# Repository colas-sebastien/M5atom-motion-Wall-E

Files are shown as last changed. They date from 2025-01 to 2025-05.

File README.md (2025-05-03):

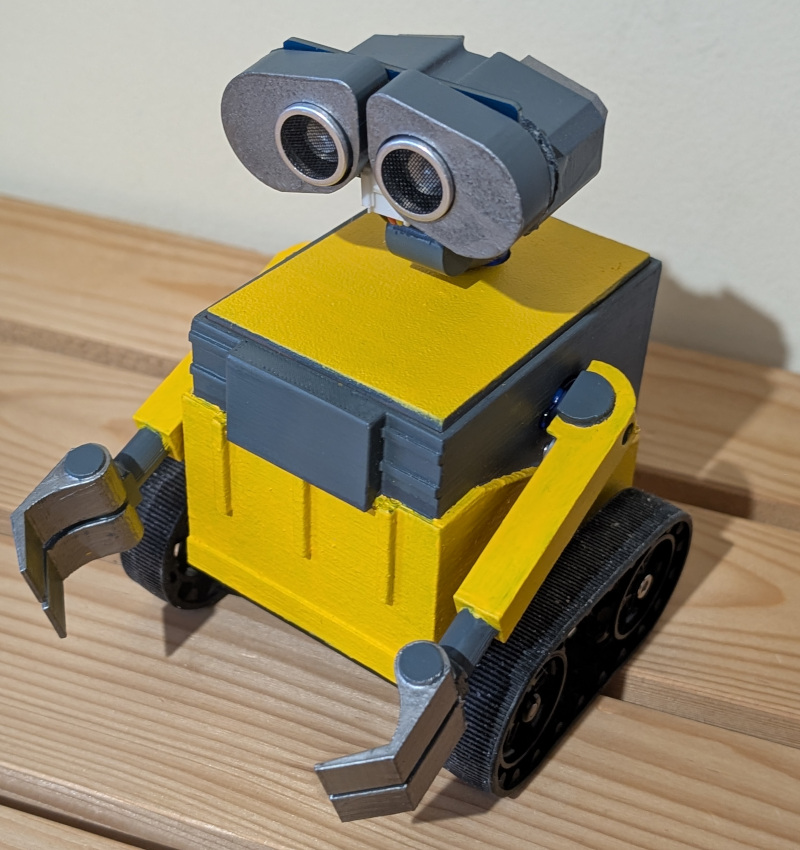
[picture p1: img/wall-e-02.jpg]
M5Atom WALL-E


# M5Atom WALL-E

Create your Wall-E thanks to M5atom

## Hardware
- [1x Zumo Chassis Kit](https://www.pololu.com/product/1418) 
- [2x Micro Metal Gearmotor HP 6V](https://www.pololu.com/product/1101) 
- [Grove - I2C Motor Driver](https://www.seeedstudio.com/Grove-I2C-Motor-Driver-TB6612FNG-p-3220.html) 
- [M5Atom](https://shop.m5stack.com/products/atomic-motion-base-stm32f030?variant=44393917219073) 
- [Atomic Motion Base](https://shop.m5stack.com/products/atom-tailbat) 
- [Battery 16340 2600mAh](https://www.amazon.fr/Rechargeables-Batterie-2800mAh-Capacit%C3%A9-Frontale/dp/B0CTQ4X244)
- [Battery holder for 16340](https://www.amazon.fr/dp/B07MC7WR8J?ref=ppx_yo2ov_dt_b_fed_asin_title)
- [3x ServoMotors sg90](https://www.amazon.fr/dp/B0DFCGXY2J)
- [Grove Ultrasonic distance sensor](https://www.seeedstudio.com/Grove-Ultrasonic-Distance-Sensor.html)
- [A bluetooth gamepad supported by BluePad32 for Arduino](https://gitlab.com/ricardoquesada/bluepad32-arduino) 

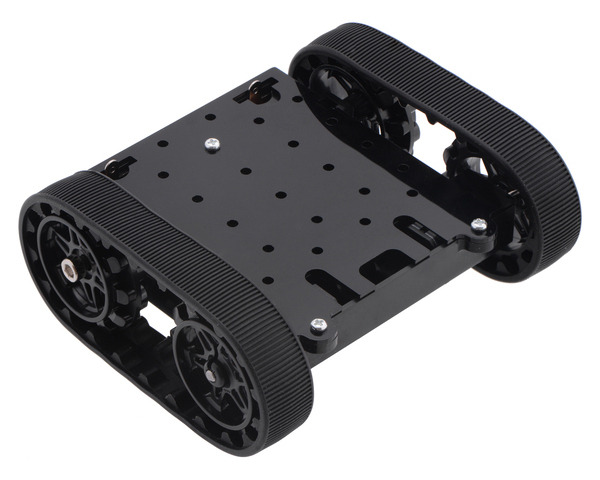
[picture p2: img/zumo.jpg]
zumo

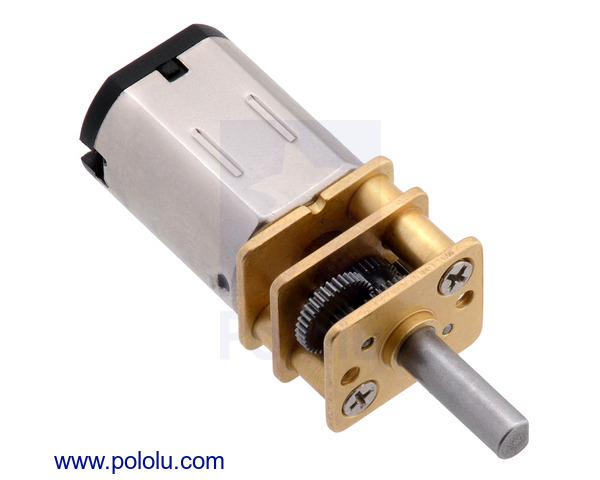
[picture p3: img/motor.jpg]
motor

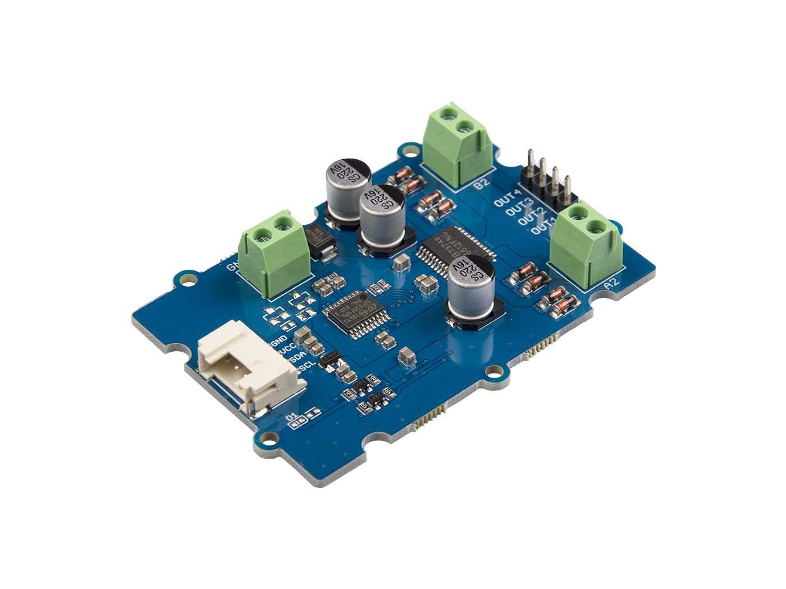
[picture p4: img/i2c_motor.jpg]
I2C motor driver

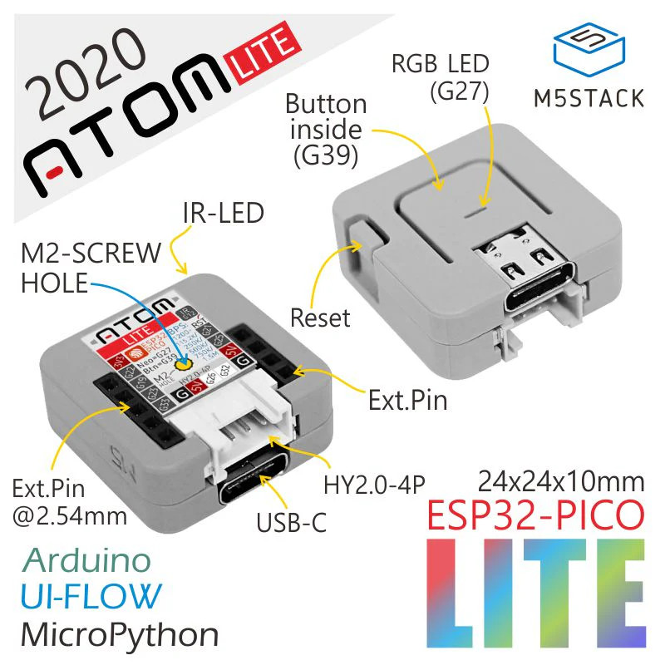
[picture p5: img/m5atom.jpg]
M5Atom lite

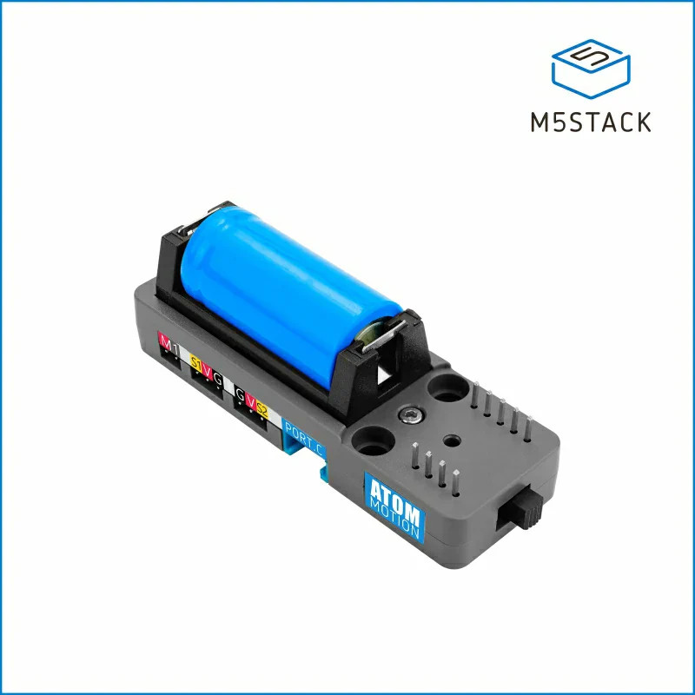
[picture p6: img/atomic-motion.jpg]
Atomic Motion Base

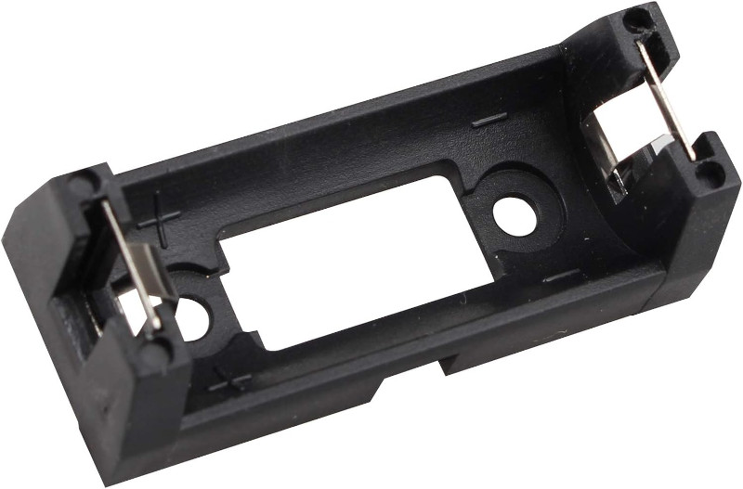
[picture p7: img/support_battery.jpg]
Battery holder for 16340

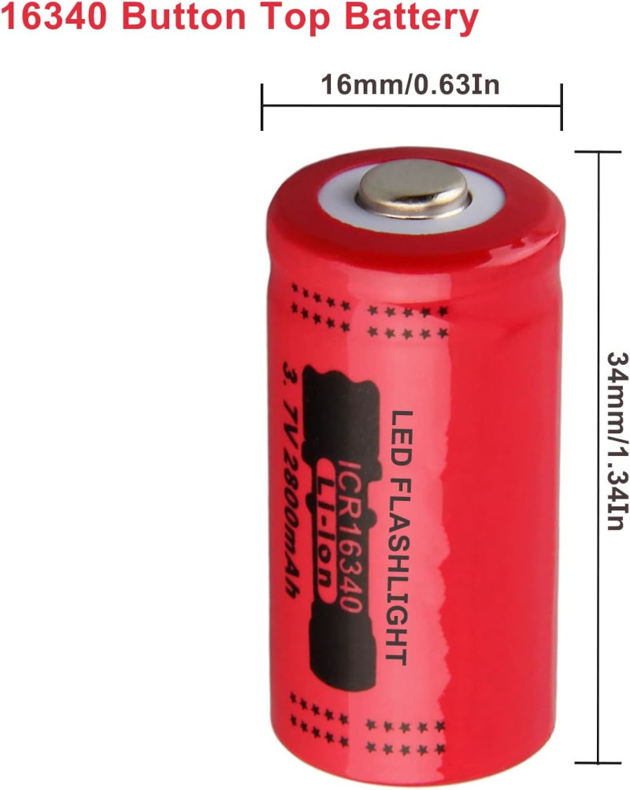
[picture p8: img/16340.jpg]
Battery 16340 2600mAh

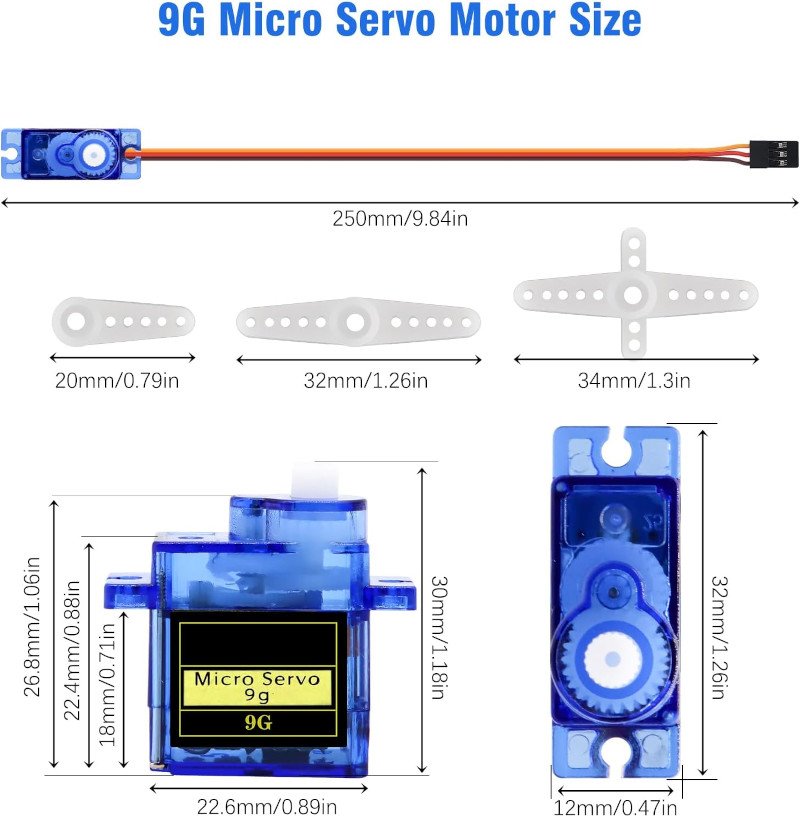
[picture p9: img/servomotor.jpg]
Servo Motor

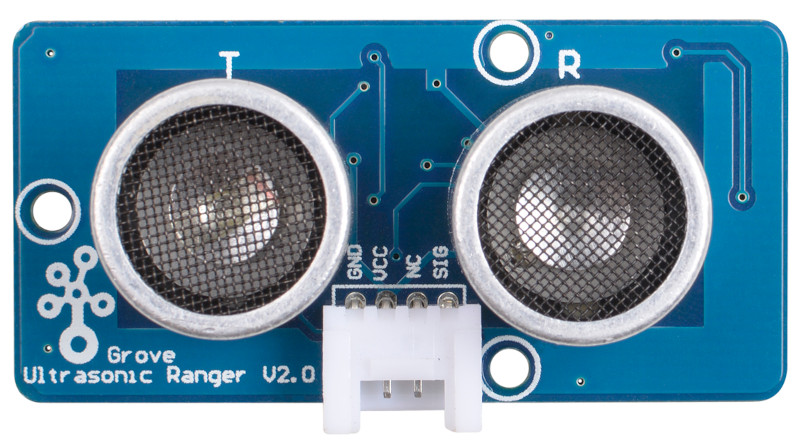
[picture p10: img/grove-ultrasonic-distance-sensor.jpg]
Grove Ultrasonic distance sensor

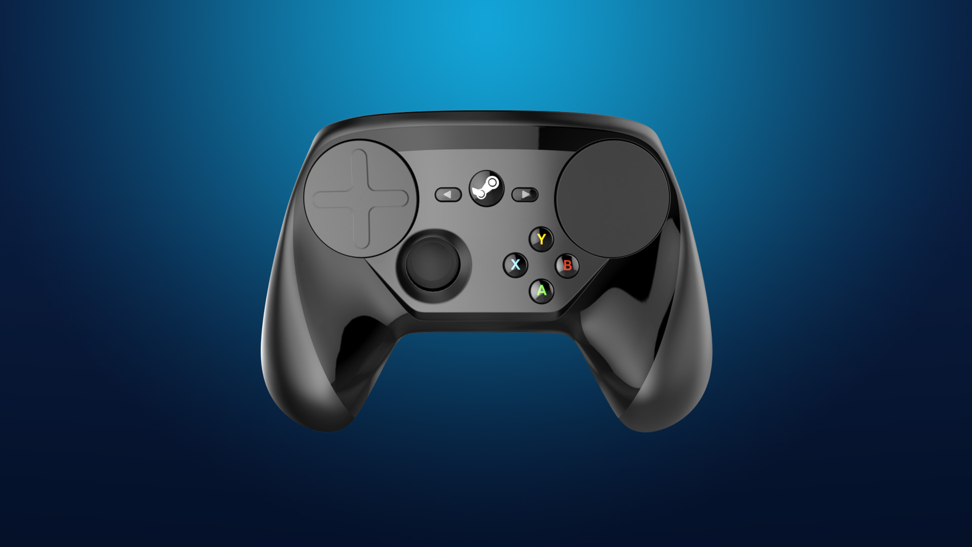
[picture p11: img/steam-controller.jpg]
Steam Controller


## 3D Model
### FreeCAD
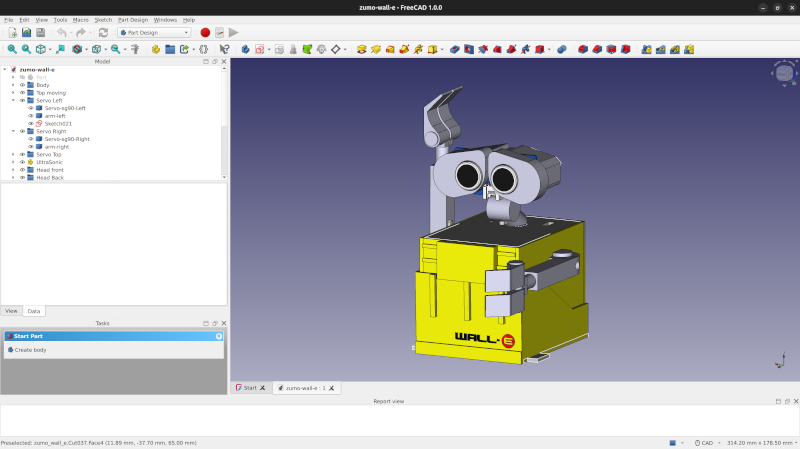
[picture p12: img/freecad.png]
FreeCAD

You can found the FreeCAD model into the *FreeCAD* directory.

### STL
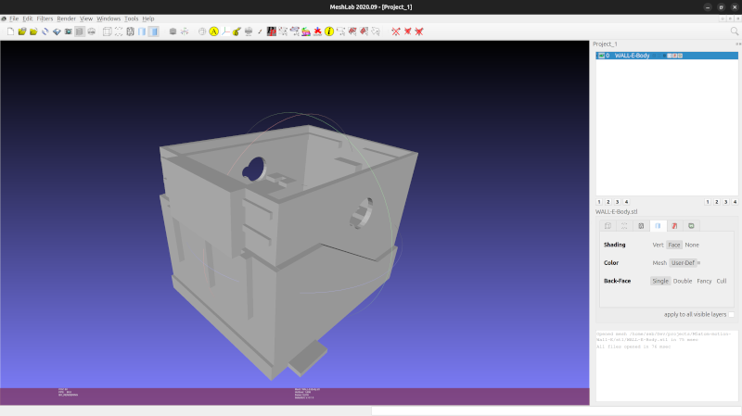
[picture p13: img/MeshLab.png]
MeshLab


You can found the FreeCAD model into the *stl* directory.

## Connect everything together
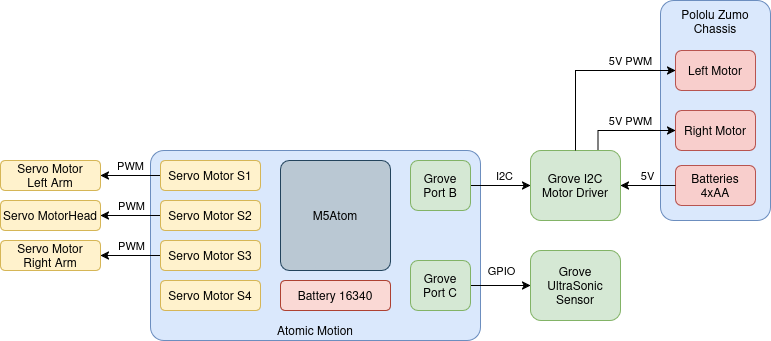
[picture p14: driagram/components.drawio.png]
Connect everything together

### Atomic Motion Modification (optional)
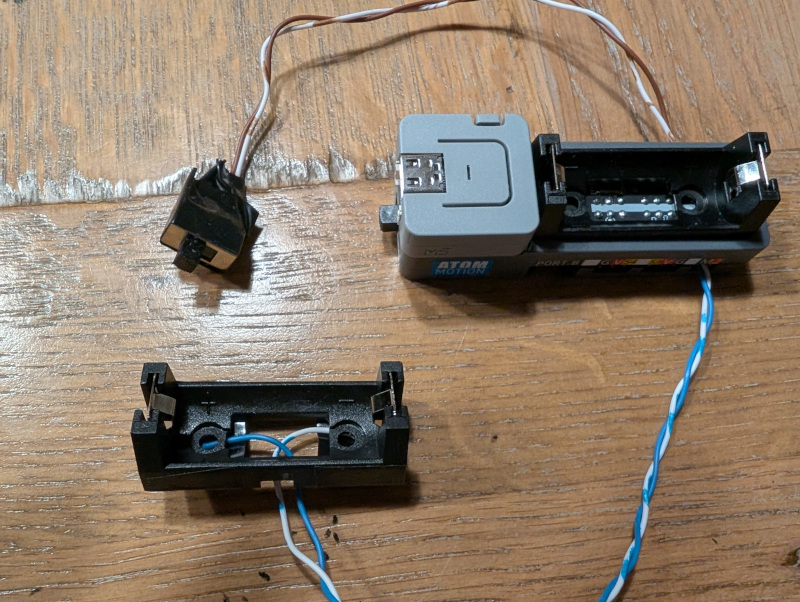
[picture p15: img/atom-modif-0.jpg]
Atom Modification

To power on/off WALL-E and easily replace the battery the following modifications can be on the Atomic module
- Add an external battery holder
- Add an external switch

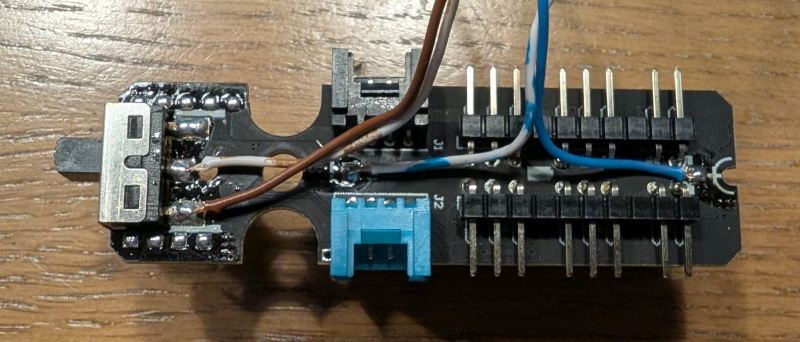
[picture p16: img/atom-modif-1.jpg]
Atom Modification


### Inside WALL-E
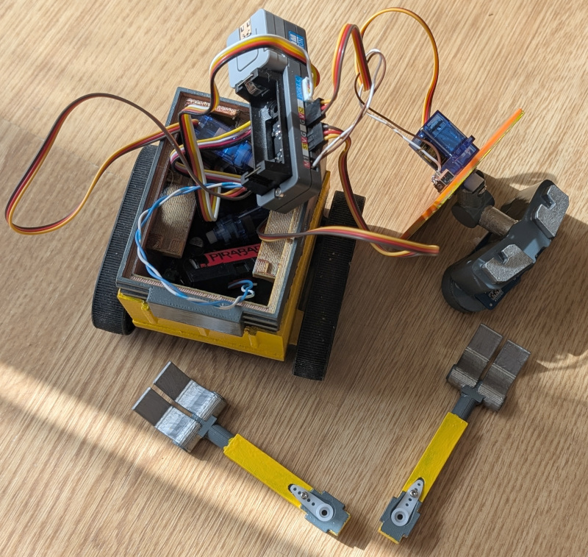
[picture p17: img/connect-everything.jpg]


## Software
- Install thanks to Board Manager: 
    - BluePad for Arduino [BluePad for Arduino](https://bluepad32.readthedocs.io/en/latest/plat_arduino/)
    - M5Stack
- Install thanks to Library Manager:
    - Grove Motor Driver TB6612FNG
    - Grove Ultrasonic Ranger
    - Adafruit NeoPixel
    - M5Atom    
- Select for Board: *ESP32 + Bluepad32 Arduino / M5Stack-ATOM*

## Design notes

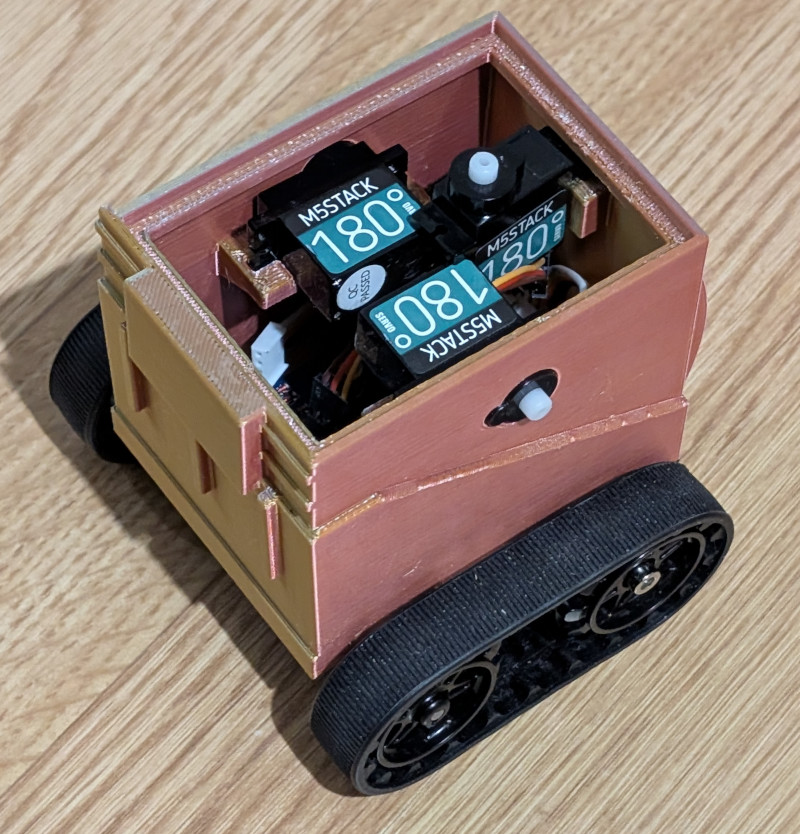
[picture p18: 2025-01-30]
img/wall-e-01.jpg

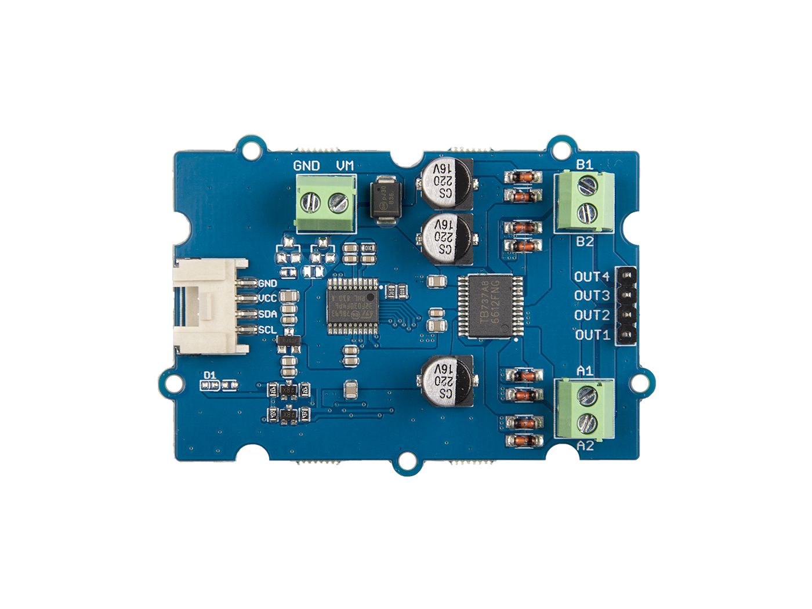
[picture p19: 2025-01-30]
img/i2c_motor_top.jpg

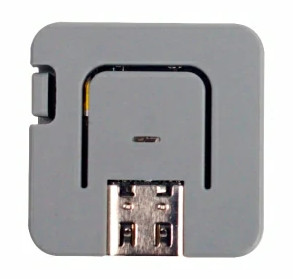
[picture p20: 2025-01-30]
img/m5atom_top.jpg

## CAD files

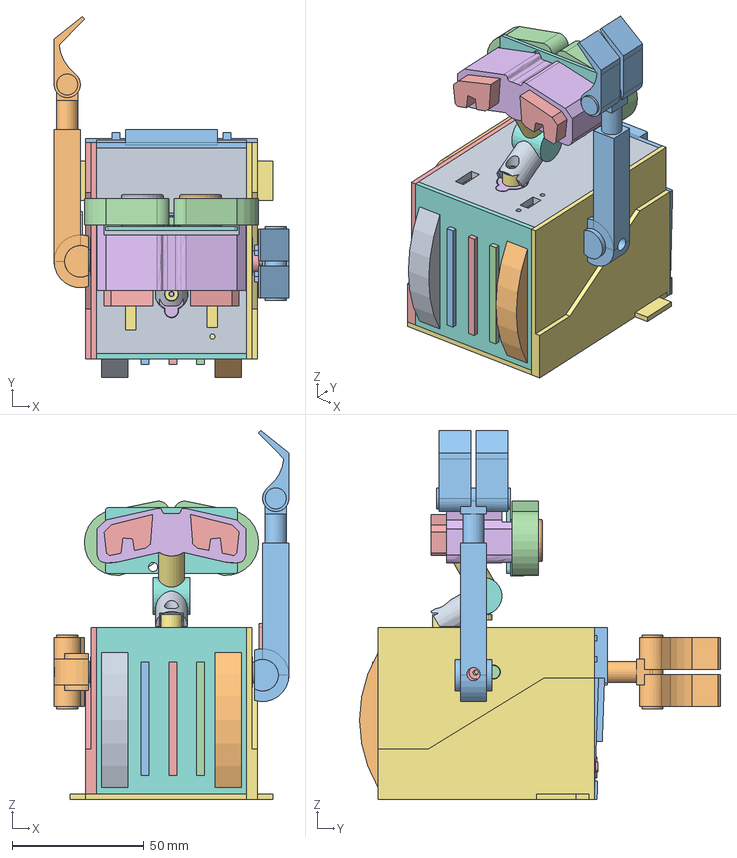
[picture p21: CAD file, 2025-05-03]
FreeCAD/zumo-wall-e.FCStd
89.0 x 136.8 x 139.9 mm
Servo-sg90-Left
arm-left
Servo-sg90-Right
arm-right
Servo-sg90-Top
arm-top
PCB
sensor
sensor001
Grove_L_connector
Back 2
arm-left001
support servo
support servo (Mirror #2)
Cut016 (Mirror #3)

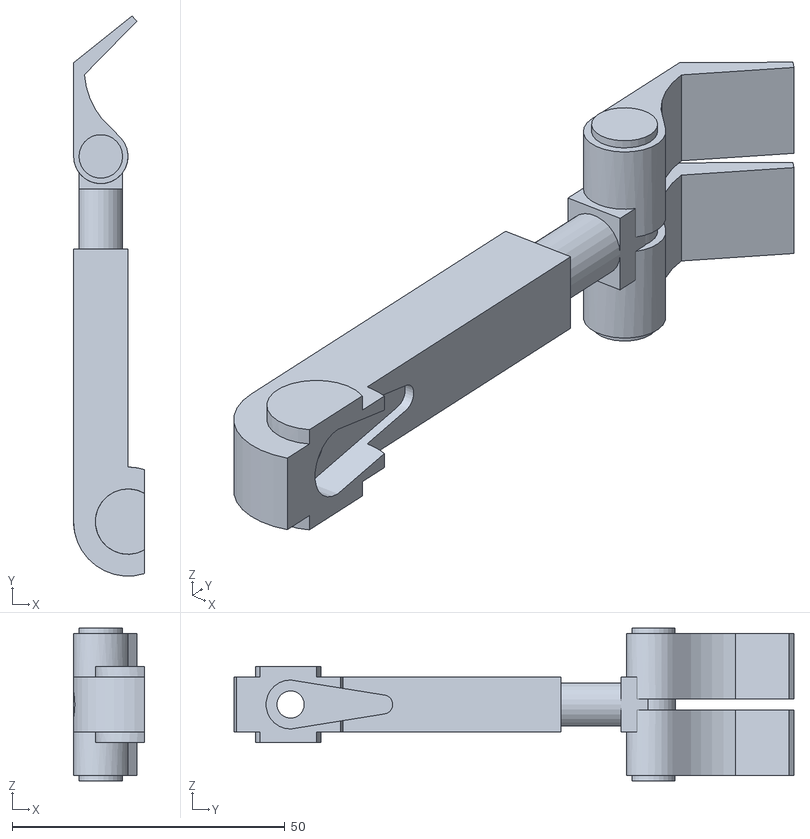
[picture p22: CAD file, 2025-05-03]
stl/WALL-E-Arm.stl
13.0 x 102.7 x 28.0

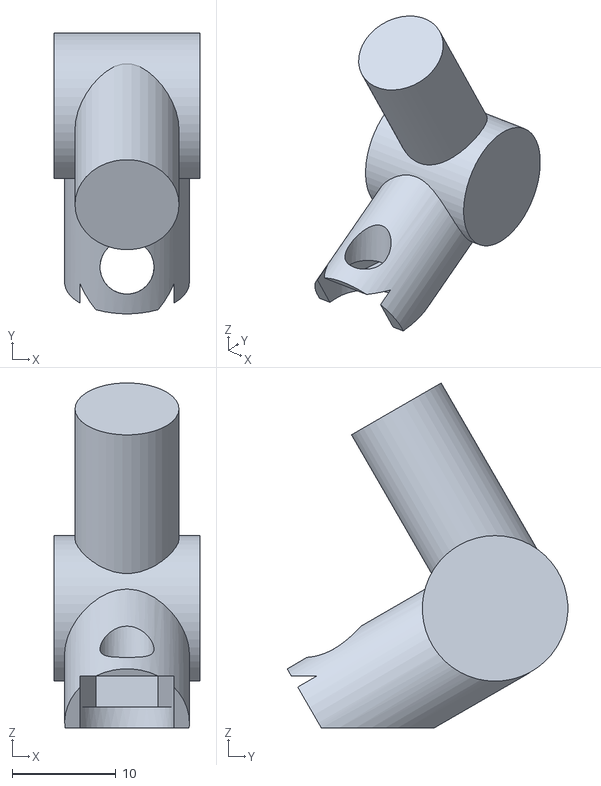
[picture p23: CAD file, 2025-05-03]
stl/WALL-E-Neck.stl
14.0 x 27.0 x 33.2

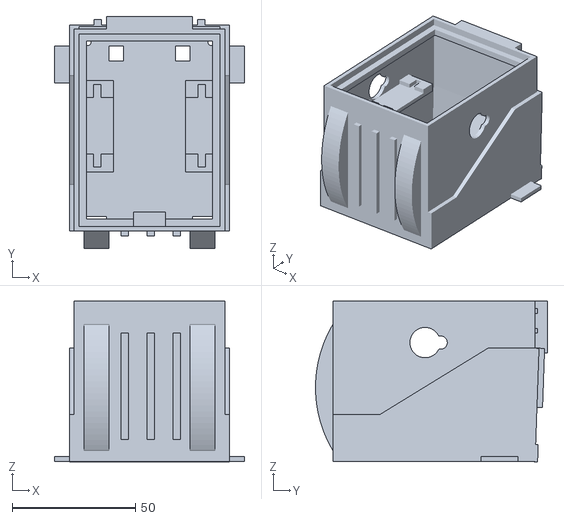
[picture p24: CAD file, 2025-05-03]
stl/WALL-E-Body.stl
77.0 x 94.0 x 65.1

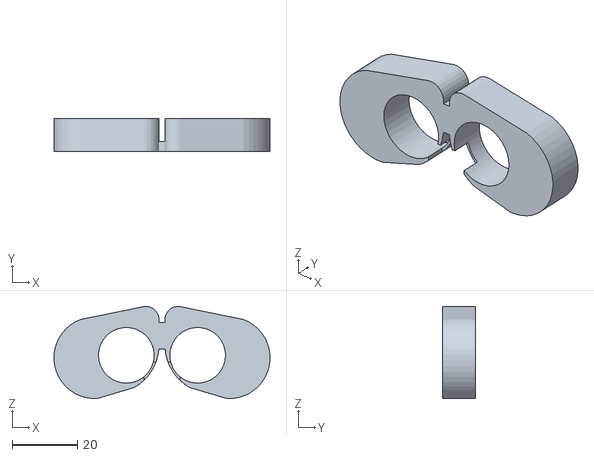
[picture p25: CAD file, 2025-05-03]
stl/WALL-E-Head-Front.stl
66.0 x 10.0 x 28.1

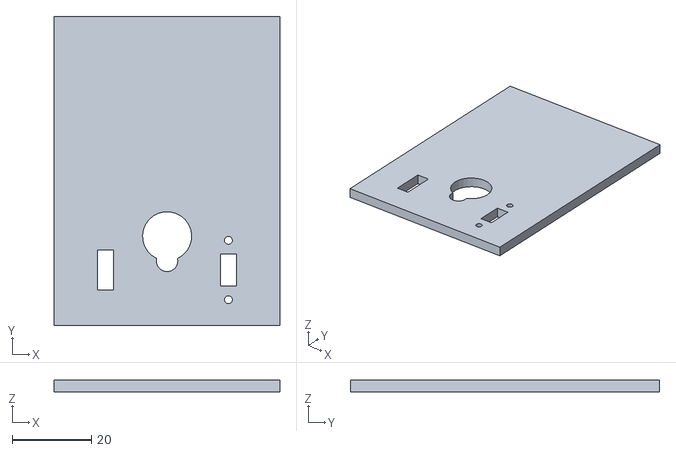
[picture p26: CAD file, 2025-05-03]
stl/WALL-E-Top.stl
57.0 x 78.0 x 3.00

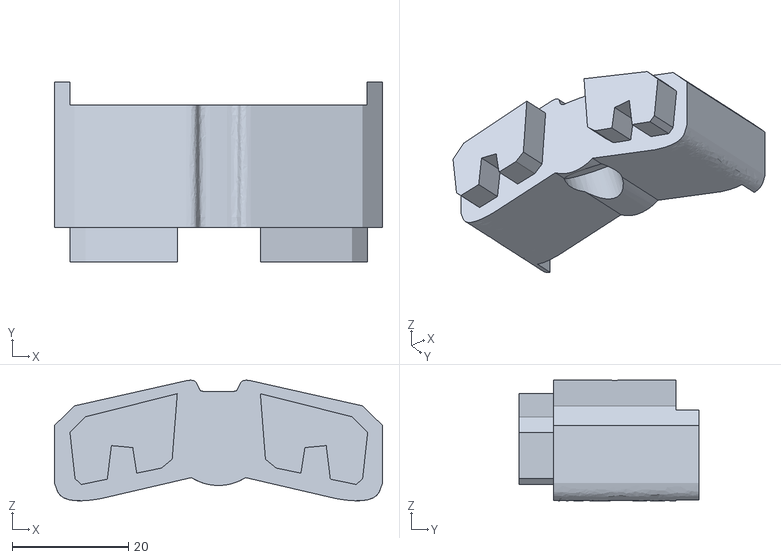
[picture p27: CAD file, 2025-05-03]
stl/WALL-E-Head-Back.stl
56.4 x 31.0 x 20.7

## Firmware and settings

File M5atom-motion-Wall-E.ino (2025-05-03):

/*

    M5 Atom WALL-E Project

    Create your own WALL-E thanks to M5 Atom / M5 Atom Echo

    Author: Sébastien Colas

 */

#include <M5Atom.h>
#include <Grove_Motor_Driver_TB6612FNG.h>
#include <Ultrasonic.h>
#include <Wire.h>
#include <Bluepad32.h>
#include <Adafruit_NeoPixel.h>
#include "AtomMotion.h"

#define PIN_RGB                 27  
#define NUMPIXELS                1   
#define GAMEPAD_DEAD_ZONE_X     50
#define GAMEPAD_DEAD_ZONE_Y     50
#define GAMEPAD_MAX_X          510
#define GAMEPAD_MAX_Y          510
#define GAMEPAD_MAX_BRAKE     1020
#define GAMEPAD_MAX_THROTTLE  1020
#define GAMEPAD_BUTTON_X         0
#define GAMEPAD_BUTTON_Y         1
#define GAMEPAD_BUTTON_A         2
#define GAMEPAD_BUTTON_B         3
#define GAMEPAD_BUTTON_L1        4
#define GAMEPAD_BUTTON_R1        5
#define GAMEPAD_BUTTON_PREV      6
#define GAMEPAD_BUTTON_NEXT      7
#define GAMEPAD_BUTTON_LOGO      8

#define MOTOR_MIN_SPEED         50
#define MOTOR_MAX_SPEED        255
#define MOTOR_A_DIR              1
#define MOTOR_B_DIR             -1

#define SMOOTH_NUMBER           20

/*
 * PORT A => PORT_SDA 26
 *           PORT_SCL 32
 *
 * For Atom Motion
 * PORT B => PORT_SDA 33
 *           PORT_SDA 23
 * PORT C => PORT_SDA 19
 *           PORT_SDA 22
 * I2C    => PORT_SDA 25
 *        => PORT_SCL 21 
 */
// PORT B for Motor Cotroller
#define PORT_SDA                  33
#define PORT_SCL                  23

// PORT C for UltraSonicSensor
#define ULTRASONIC_PORT           22

Adafruit_NeoPixel pixels = Adafruit_NeoPixel( NUMPIXELS, PIN_RGB,NEO_GRB + NEO_KHZ800);

ControllerPtr myControllers[BP32_MAX_CONTROLLERS];
MotorDriver motor;

AtomMotion Atom;
bool direction = true;
Ultrasonic ultrasonic(ULTRASONIC_PORT);
long RangeInCentimeters;

bool    buttons[9] = {false, false, false, false, false, false, false, false, false};
//      Buttons         X      Y      A      B     L1     R1     PREV   NEXT   LOGO

int32_t hands_values[2][SMOOTH_NUMBER];
int8_t  hands_index=0;

int32_t smooth_value(int32_t *values)
{
  int32_t value =    0;
  int32_t min   = 1000;
  int32_t max   =    0;
  int32_t sum   =    0;

  for (int32_t i=0;i<SMOOTH_NUMBER;i++)
  {
    if (values[i]<min)
    {
      min=values[i];
    }
    if (values[i]>max)
    {
      max=values[i];
    }
    sum+=values[i]; 
  }
  return round((sum-min-max)/(SMOOTH_NUMBER-2));
}

bool button_pressed(bool state,uint8_t id)
{
  bool pressed=false;
  if (state)                      // Button is currently pressed
  {                               
    if (buttons[id])              // Button is still pressed 
    {
                                  // Nothing to to
    }
    else                          // Button was previously  not pressed
    {
      buttons[id]=true;
      pressed=true;   
    }    
  }
  else
  {
    buttons[id]=false;
  }
  return pressed;
}

void GetServoStatus() 
{
    for (int ch = 1; ch < 4; ch++) 
    {
        Serial.printf("Servo Channel %d: %d \n", ch, Atom.ReadServoAngle(ch));
    }
}

void setup() {

  for (int i=0;i<SMOOTH_NUMBER;i++)
  {
    hands_values[0][i]=0;
    hands_values[1][i]=0;
  }
  M5.begin(true,false);
  Atom.Init();  
  pixels.begin();
  pixels.setPixelColor(0,0,0,200);
  pixels.show();
  Wire.begin(PORT_SDA, PORT_SCL);
  Serial.begin(115200);
  while (!Serial) {
    ;
  }  

  Serial.println();
  Serial.println("M5Atom Wall-E");

  String fv = BP32.firmwareVersion();
  Serial.print("Firmware version installed: ");
  Serial.println(fv);

  // To get the BD Address (MAC address) call:
  const uint8_t* addr = BP32.localBdAddress();
  Serial.print("BD Address: ");
  for (int i = 0; i < 6; i++) {
    Serial.print(addr[i], HEX);
    if (i < 5)
      Serial.print(":");
    else
      Serial.println();
  }

  motor.init();  

  BP32.setup(&onConnectedController, &onDisconnectedController);
  BP32.forgetBluetoothKeys();       
}

void onConnectedController(ControllerPtr ctl) {
  bool foundEmptySlot = false;

  pixels.setPixelColor(0,0,50,0);
  pixels.show();

  for (int i = 0; i < BP32_MAX_GAMEPADS; i++) {
    if (myControllers[i] == nullptr) {
      Serial.print("CALLBACK: Controller is connected, index=");
      Serial.println(i);
      myControllers[i] = ctl;
      foundEmptySlot = true;

      // Optional, once the gamepad is connected, request further info about the
      // gamepad.
      ControllerProperties properties = ctl->getProperties();
      char buf[80];
      sprintf(buf,
              "BTAddr: %02x:%02x:%02x:%02x:%02x:%02x, VID/PID: %04x:%04x, "
              "flags: 0x%02x",
              properties.btaddr[0], properties.btaddr[1], properties.btaddr[2],
              properties.btaddr[3], properties.btaddr[4], properties.btaddr[5],
              properties.vendor_id, properties.product_id, properties.flags);
      Serial.println(buf);
      break;
    }
  }
  if (!foundEmptySlot) {
    Serial.println(
        "CALLBACK: Controller connected, but could not found empty slot");
  }
}

void onDisconnectedController(ControllerPtr ctl) {
  bool foundGamepad = false;
  
  pixels.setPixelColor(0,100,0,0);
  pixels.show();

  for (int i = 0; i < BP32_MAX_GAMEPADS; i++) {
    if (myControllers[i] == ctl) {
      Serial.print("CALLBACK: Controller is disconnected from index=");
      Serial.println(i);
      myControllers[i] = nullptr;
      foundGamepad = true;
      break;
    }
  }

  if (!foundGamepad) {
    Serial.println(
        "CALLBACK: Controller disconnected, but not found in myControllers");
  }
}

bool    head_pos      = true;
bool    hand_manual   = false;
bool    hand_left_up  = false;
bool    hand_right_up = false;


void processGamepad(ControllerPtr gamepad) {
  
  int16_t speed_x;
  int16_t speed_y;

  if (hand_manual)
  { 
    hands_values[0][hands_index]=gamepad->brake();
    hands_values[1][hands_index]=gamepad->throttle();

    hands_index=(hands_index+1)%SMOOTH_NUMBER;    
    
    Atom.SetServoAngle(1, 180-smooth_value(hands_values[0])*120/GAMEPAD_MAX_BRAKE);        // Left Hand
    Atom.SetServoAngle(3, 0  +smooth_value(hands_values[1])*120/GAMEPAD_MAX_THROTTLE);     // Right Hand
  }

  if (button_pressed(gamepad->a(),GAMEPAD_BUTTON_A))                // A pressed
  {                                                                 // Hands down + Head front
    Atom.SetServoAngle(1, 180);                                     // Left Hand
    Atom.SetServoAngle(3, 0  );                                     // Right Hand
    Atom.SetServoAngle(2, 90);                                      // Head Front
  }

  if (button_pressed(gamepad->b(),GAMEPAD_BUTTON_B))                // B pressed
  {                         
    hand_manual=!hand_manual;                                       // Activating hand movement control by triggers
  }

  if (button_pressed(gamepad->x(),GAMEPAD_BUTTON_X))                // X pressed
  {
    Atom.SetServoAngle(1,   0);                                     // Left Hand Rear
    Atom.SetServoAngle(3, 180);                                     // Right Hand Rear
    Atom.SetServoAngle(2, 90);                                      // Head Front           
  }

  if (button_pressed(gamepad->y(),GAMEPAD_BUTTON_Y))               // Y pressed
  {
    head_pos=!head_pos;
    if (head_pos)
    {
      Atom.SetServoAngle(2, 110);
    }
    else
    {
      Atom.SetServoAngle(2, 70);
    }
  }

  if (button_pressed(gamepad->l1(),GAMEPAD_BUTTON_L1))              // Left Button pressed
  {                               
      hand_left_up=!hand_left_up;                                   // Move up or down the left hand
      hand_manual=false;                                            // Take over manual control
      if (hand_left_up)
      {
        Atom.SetServoAngle(1, 180-120);
      }
      else
      {
        Atom.SetServoAngle(1, 180);
      }
  }

  if (button_pressed(gamepad->r1(),GAMEPAD_BUTTON_R1))              // Rigth Button pressed
  {                               
      hand_right_up=!hand_right_up;                                 // Move up or down the left hand
      hand_manual=false;                                            // Take over manual control
      if (hand_right_up)
      {
        Atom.SetServoAngle(3, 0+120);
      }
      else
      {
        Atom.SetServoAngle(3, 0);
      }
  }

  if (button_pressed(gamepad->miscBack(),GAMEPAD_BUTTON_PREV))     // Left Button pressed
  {                               
      hand_left_up=true;                                            // Move up the left hand up
      hand_manual=false;                                            // Take over manual control
      Atom.SetServoAngle(1, 180-120);                               // Left hand up
      hand_right_up=false;                                          // Move the right hand down
      Atom.SetServoAngle(3, 0);                                     // Right hand down
      head_pos=false;                                               // Move Head to the right
      Atom.SetServoAngle(2, 70);                                    // Head to the right

  }

  if (button_pressed(gamepad->miscHome(),GAMEPAD_BUTTON_NEXT))      // Rigth Button pressed
  {                               
      hand_left_up=false;                                           // Move up the left hand down
      hand_manual=false;                                            // Take over manual control
      Atom.SetServoAngle(1, 180);                                   // Left hand down
      hand_right_up=true;                                           // Move the right hand down
      Atom.SetServoAngle(3, 0+120);                                 // Right hand up
      head_pos=true;                                                // Move Head to the right
      Atom.SetServoAngle(2, 110);                                   // Head to the right
  }  


  speed_x=MOTOR_MIN_SPEED+(abs(gamepad->axisX())-GAMEPAD_DEAD_ZONE_X)*MOTOR_MAX_SPEED/GAMEPAD_MAX_X;
  speed_y=MOTOR_MIN_SPEED+(abs(gamepad->axisY())-GAMEPAD_DEAD_ZONE_Y)*MOTOR_MAX_SPEED/GAMEPAD_MAX_Y;
  
  if (gamepad->axisY()<-GAMEPAD_DEAD_ZONE_Y) {          // FORWARD
    if (gamepad->axisX()<-200) {                        //  + LEFT
      motor.dcMotorRun(MOTOR_CHA, -speed_y*MOTOR_A_DIR);
      motor.dcMotorRun(MOTOR_CHB, -(speed_y-speed_x+MOTOR_MIN_SPEED)*MOTOR_B_DIR);
    }
    else if (gamepad->axisX()>200) {                    //  + RIGHT
      motor.dcMotorRun(MOTOR_CHA, -(speed_y-speed_x+MOTOR_MIN_SPEED)*MOTOR_A_DIR);
      motor.dcMotorRun(MOTOR_CHB, -speed_y*MOTOR_B_DIR);
    }
    else
    {
      motor.dcMotorRun(MOTOR_CHA, -speed_y*MOTOR_A_DIR);
      motor.dcMotorRun(MOTOR_CHB, -speed_y*MOTOR_B_DIR);    
    }
  }
  else if (gamepad->axisY()>GAMEPAD_DEAD_ZONE_Y) {      // BACKWARD    
    motor.dcMotorRun(MOTOR_CHA,  speed_y*MOTOR_A_DIR);
    motor.dcMotorRun(MOTOR_CHB,  speed_y*MOTOR_B_DIR);
  }
  else  if (gamepad->axisX()<-GAMEPAD_DEAD_ZONE_X) {    // LEFT
    motor.dcMotorRun(MOTOR_CHA, -150*MOTOR_A_DIR);
    motor.dcMotorRun(MOTOR_CHB,  150*MOTOR_B_DIR);
  }
  else   if (gamepad->axisX()>GAMEPAD_DEAD_ZONE_Y) {    // RIGHT
    motor.dcMotorRun(MOTOR_CHA,  150*MOTOR_A_DIR);
    motor.dcMotorRun(MOTOR_CHB, -150*MOTOR_B_DIR);
  } 
  else {                                // STOP
    motor.dcMotorStop(MOTOR_CHA);
    motor.dcMotorStop(MOTOR_CHB);
  }
}



void loop()
{
  BP32.update();

  // It is safe to always do this before using the controller API.
  // This guarantees that the controller is valid and connected.
  for (int i = 0; i < BP32_MAX_CONTROLLERS; i++) {
    ControllerPtr myController = myControllers[i];

    if (myController && myController->isConnected()) {
      if (myController->isGamepad())
        processGamepad(myController);
    }
  }

  // RangeInCentimeters = ultrasonic.MeasureInCentimeters(); // two measurements should keep an interval
  // Serial.print(RangeInCentimeters);//0~400cm
  // Serial.println(" cm");  

  delay(10);
}

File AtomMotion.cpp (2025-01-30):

#include "AtomMotion.h"

void AtomMotion::Init() {
    Wire1.begin(25, 21);
}

void AtomMotion::Write1Byte(uint8_t address, uint8_t Register_address,
                            uint8_t data) {
    Wire1.beginTransmission(address);
    Wire1.write(Register_address);
    Wire1.write(data);
    Wire1.endTransmission();
}

void AtomMotion::Write2Byte(uint8_t address, uint8_t Register_address,
                            uint16_t data) {
    Wire1.beginTransmission(address);
    Wire1.write(Register_address);
    Wire1.write(data >> 8);    // MSB
    Wire1.write(data & 0xFF);  // LSB

    Wire1.endTransmission();
}

uint8_t AtomMotion::ReadBytes(uint8_t address, uint8_t subAddress,
                              uint8_t count, uint8_t *dest) {
    Wire1.beginTransmission(address);  // Initialize the Tx buffer
    Wire1.write(subAddress);           // Put slave register address in Tx buffer
    uint8_t i = 0;
    if (Wire1.endTransmission(false) == 0 &&
        Wire1.requestFrom(address, (uint8_t)count)) {
        while (Wire1.available()) {
            dest[i++] = Wire1.read();
        }
        return true;
    }
    return false;
}

/*******************************************************************************/

uint8_t AtomMotion::SetServoAngle(uint8_t Servo_CH, uint8_t angle) {
    uint8_t Register_address = Servo_CH - 1;
    if (Register_address > 3) return 0;
    Write1Byte(SERVO_ADDRESS, Register_address, angle);
    return 0;
}

uint8_t AtomMotion::SetServoPulse(uint8_t Servo_CH,
                                  uint16_t width)  // 0x10        ->16
{
    uint8_t servo_ch         = Servo_CH - 1;
    uint8_t Register_address = 2 * servo_ch + 16;
    if (Register_address % 2 == 1 || Register_address > 32) return 1;
    Write2Byte(SERVO_ADDRESS, Register_address, width);
    return 0;
}

uint8_t AtomMotion::SetMotorSpeed(uint8_t Motor_CH, int8_t speed)  // 0x10 ->16
{
    uint8_t servo_ch = Motor_CH - 1;
    if (servo_ch > 1) return 1;
    uint8_t Register_address = servo_ch + 32;
    Write1Byte(SERVO_ADDRESS, Register_address, (uint8_t)speed);
    return 0;
}

uint8_t AtomMotion::ReadServoAngle(uint8_t Servo_CH) {
    uint8_t data             = 0;
    uint8_t Register_address = Servo_CH - 1;
    ReadBytes(SERVO_ADDRESS, Register_address, 1, &data);
    return data;
}

uint16_t AtomMotion::ReadServoPulse(uint8_t Servo_CH) {
    uint8_t data[2];
    uint8_t servo_ch         = Servo_CH - 1;
    uint8_t Register_address = 2 * servo_ch | 0x10;
    ReadBytes(SERVO_ADDRESS, Register_address, 2, data);
    return (data[0] << 8) + data[1];
}

int8_t AtomMotion::ReadMotorSpeed(uint8_t Motor_CH) {
    int8_t data      = 0;
    uint8_t servo_ch = Motor_CH - 1;
    if (servo_ch > 1) return 1;
    uint8_t Register_address = servo_ch | 0x20;
    ReadBytes(SERVO_ADDRESS, Register_address, 1, (uint8_t *)&data);
    return data;
}

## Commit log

2025-04-27 Motor directions can be configured + new photo of the project
2025-05-02 Version 1 (without ultrasonic)
2025-05-03 Documentation update
    [WALL-E-Arm.stl, WALL-E-Body.stl, WALL-E-Head-Back.stl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]
